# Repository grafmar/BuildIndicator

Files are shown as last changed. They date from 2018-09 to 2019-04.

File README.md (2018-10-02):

# Build Indicator
This device can show the state of builds or any other thing stored in the firebase database. It can
be configured, which part indicates what and lets the oportunity to meld fields together.

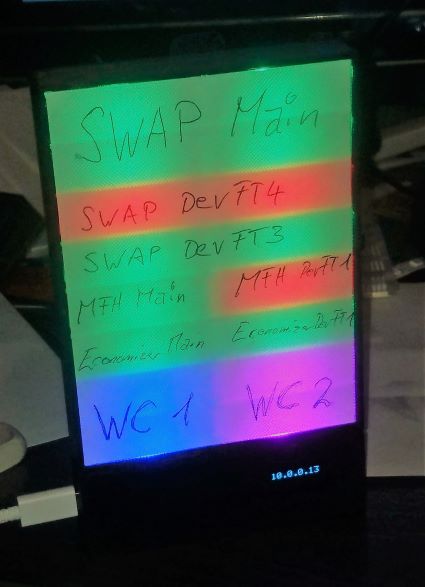
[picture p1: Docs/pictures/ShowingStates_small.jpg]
Build Indicator showing states


## Status
The actual status of the software is still buggy. It resets if the streaming from the firebase is activated.

## Requirements
* [Arduino IDE](https://www.arduino.cc/en/main/software)
* [ESP8266 board support](https://github.com/arduino/Arduino/wiki/Unofficial-list-of-3rd-party-boards-support-urls): http://arduino.esp8266.com/stable/package_esp8266com_index.json
* [FirebaseArduino library](https://github.com/FirebaseExtended/firebase-arduino)
* ArduinoJson library Version 5.13.1 (higher versions result in problems with the active FirebaseArduino library)
* Adafruit_NeoPixel library
* Adafruit_GFX library
* Adafruit_SSD1306 library
* WiFiManager library
* [Visual Studio](https://visualstudio.microsoft.com/) to have a comfortable IDE
* [Visual Micro](https://www.visualmicro.com/) to integrate Arduino IDE in Visual Studio

## Hardware
The hardware consists of:
* NodeMCU board (any ESP8266 board would do)
* WS2812b programmable RGB-LED stripes 2x8 in series
* SSD1306 OLED display (128x64 pixel)

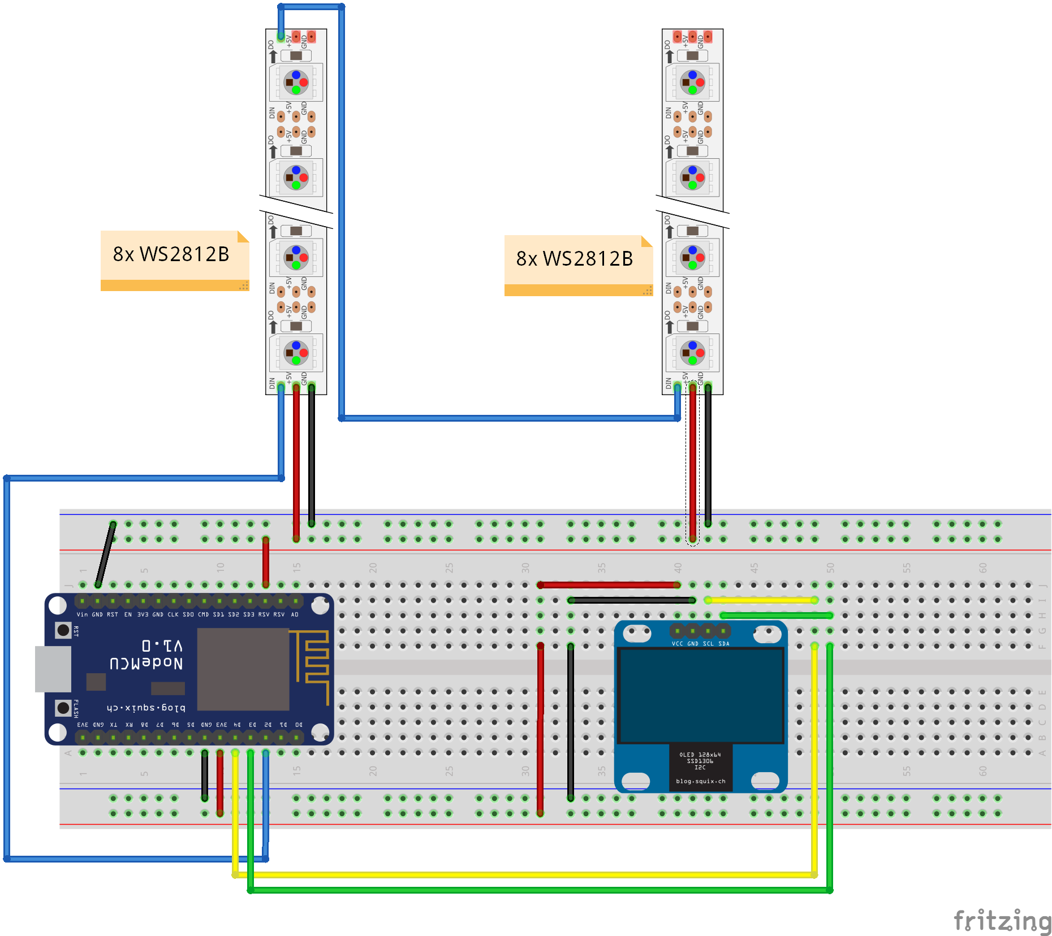
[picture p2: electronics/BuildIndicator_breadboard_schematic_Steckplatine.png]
Schematic


## Housing / Enclosure
The housing is printed using a 3D-Printer. There is a slit to slide in a transparent foil to write
the lamp configurations on. As background a transparent material can be used for the 3D-printer or
a thin paper which can be laminated for durability.
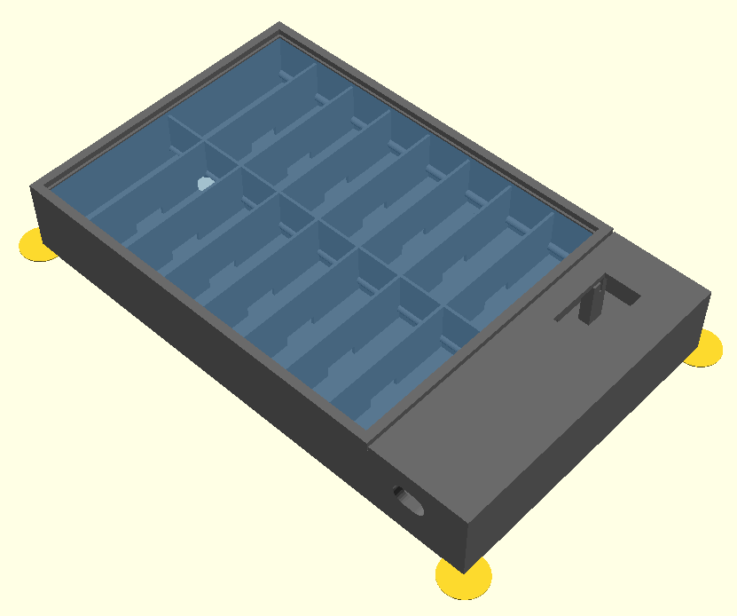
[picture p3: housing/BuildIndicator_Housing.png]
Housing complete

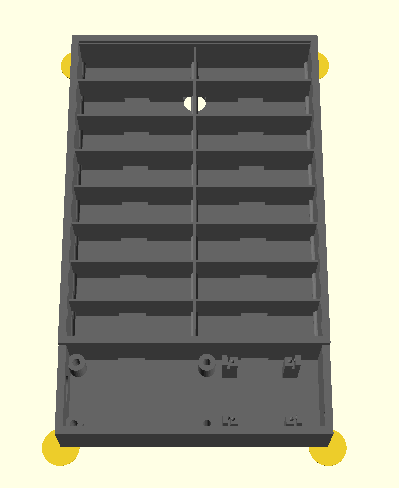
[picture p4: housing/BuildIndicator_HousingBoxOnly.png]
Housing box only


## Author
[Marco Graf](https://github.com/grafmar)

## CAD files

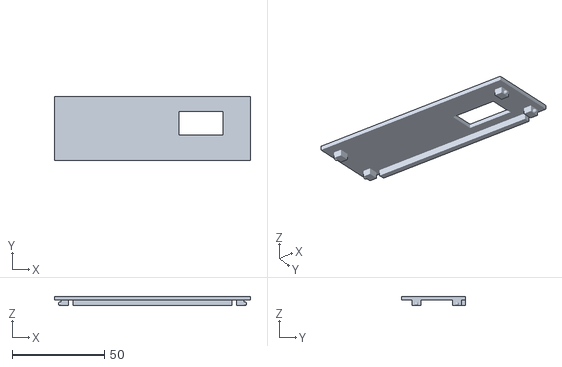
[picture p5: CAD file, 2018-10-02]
housing/BuildIndicatorBox_BoxCover.stl
106.0 x 34.5 x 5.00

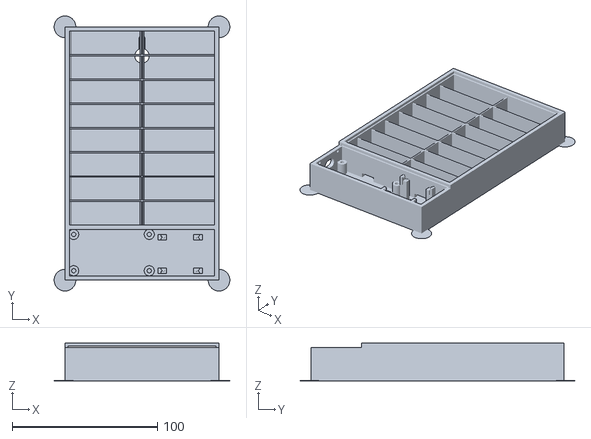
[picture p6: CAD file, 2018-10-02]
housing/BuildIndicatorBox_Box.stl
121.0 x 189.3 x 26.0

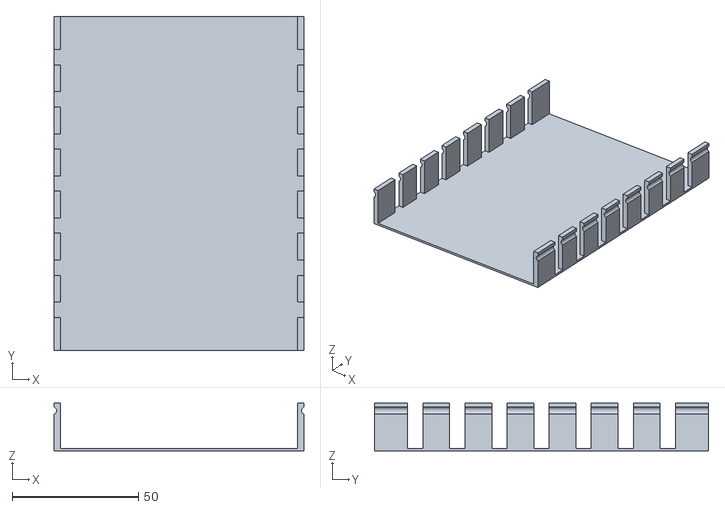
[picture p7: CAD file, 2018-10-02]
housing/BuildIndicatorBox_Diffusor.stl
99.0 x 132.3 x 19.0

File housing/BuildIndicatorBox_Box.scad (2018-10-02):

ledRows = 8;        // number of LED-rows
ledCols = 2;        // number of LED-columns
wall = 3;           // wall sickness [mm]
separator = 1;      // separator thickness [mm]
ledWidth = 50;      // width of 1 LED-indication segment
ledHeight = 50/3;   // height of 1 LED-indication segment (1.67mm LED pitch)
ledDepth = 20;      // depth of 1 LED indication segment (Box thickness = ledDepth+wall)
hookThickness = 2;

$fs=.5;
/*intersection(){
    translate([55,-40,-1]){cube([50,45,30]);}
    box();
}*/
box();
//translate([0,0,0]){boxCover();}
//translate([wall,ledHeight*ledRows+wall,ledDepth+wall]){rotate([180,0,0]){diffusor();}}
//diffusor();

/*
difference() {
    union() {
        box();
        translate([wall,ledHeight*ledRows+wall,ledDepth+wall]){rotate([180,0,0]){diffusor();}}
    }
    sphere(r=60,$fn=200);
}
*/

module hook() {
  translate([0,-2.5,-3]){cube([2, 5, 3],center=false);}
  hull() {
    translate([0,0,-2]){sphere(r=1);}
    translate([-0.5,0,-2]){sphere(r=1);}
  }
}

module boxCover() {
  boxWidth = ledWidth*ledCols + 2*wall;
  boxHeight = ledHeight*ledRows + 2*wall;
  dispCenterX = wall+3+52+10 + 22.5/2;
  dispCenterY = -32/2 -25/2 + 23/2 + 2.1;
  color("DimGray") {
    difference() {
      translate([0,-(32+wall),ledDepth+wall]){cube([boxWidth, 32+wall-0.5, 2]);}
      translate([dispCenterX, dispCenterY, ledDepth+wall]){cube([21.8+2, 10.9+2, 3*ledDepth], center=true);}
/*
    // Mounting holes Display
      -(32+wall)
    translate([wall+3+52+10,-32/2-25/2,wall]){nodeMCUMountingHole(ledDepth-3.5);}
    translate([wall+3+52+10,-32/2-25/2+23,wall]){nodeMCUMountingHole(ledDepth-3.5);}
    translate([wall+3+52+10+22.5,-32/2-25/2,wall]){nodeMCUMountingHole(ledDepth-3.5);}
    translate([wall+3+52+10+22.5,-32/2-25/2+23,wall]){nodeMCUMountingHole(ledDepth-3.5);}
*/
    }
    
    // stiffener
      translate([10,-wall-0.5,ledDepth]){cube([boxWidth-20, wall, wall]);}
    
    
    // hooks
    translate([wall+0.5,-32 + 5,ledDepth+wall]){hook();}
    translate([boxWidth-wall-0.5,-32 + 5,ledDepth+wall]){rotate([0,0,180]){hook();}}
    translate([wall+0.5,- 5,ledDepth+wall]){hook();}
    translate([boxWidth-wall-0.5,- 5,ledDepth+wall]){rotate([0,0,180]){hook();}}
  }
}

module box() {
  boxWidth = ledWidth*ledCols + 2*wall;
  boxHeight = ledHeight*ledRows + 2*wall;
    
  // Bodenhaltung
  bhDia=15;
  bhH=0.3;
  translate([0, -(32+wall),0]){cylinder(d=bhDia,h=bhH);}
  translate([boxWidth, -(32+wall),0]){cylinder(d=bhDia,h=bhH);}
  translate([0, boxHeight,0]){cylinder(d=bhDia,h=bhH);}
  translate([boxWidth, boxHeight,0]){cylinder(d=bhDia,h=bhH);}
  
  color("DimGray"){
    // LED-Part
    difference() {
      union() {
        difference() {
          cube([boxWidth, boxHeight, ledDepth+wall+3]);
          translate([wall,wall,wall]){cube([boxWidth-2*wall, boxHeight-2*wall, ledDepth+wall+3]);}
          // slit
          translate([wall-1,-1,ledDepth+wall]){cube([boxWidth-2*wall+2, boxHeight+2, 1]);}
        }
        // separators
        for(row=[1:ledRows-1]) {
          translate([0,wall+row*ledHeight-separator/2,0]){
            cube([boxWidth, separator, ledDepth+wall-2]);
          }
        }
        // separators
        for(col=[1:ledCols-1]) {
          translate([wall+col*ledWidth-separator/2,0,0]){
            cube([separator, boxHeight, ledDepth+wall-2]);
          }
        }
        // add hooks
        for(col=[0:ledCols]) {
          translate([wall+col*ledWidth,0,wall+2+2*separator]){
            rotate([-90,0,0]){cylinder(d=3*separator,h=boxHeight,$fs=.5);}
          }
        }
      }

      // Mounting hole
      translate([boxWidth/2,boxHeight-20,-wall+1]){cylinder(d=10,h=2*wall);}
      hull() {
        translate([boxWidth/2,boxHeight-20,-wall+1]){cylinder(d=4,h=2*wall);}
        translate([boxWidth/2,boxHeight-wall-5,-wall+1]){cylinder(d=4,h=2*wall);}
      }
      hull() {
        translate([boxWidth/2,boxHeight-20,wall+.001]){cylinder(d=10,h=4);}
        translate([boxWidth/2,boxHeight-wall-5,wall+.001]){cylinder(d=10,h=4);}
      }
      // LED-Stripe holes
      for(col=[0:ledCols-1]) {
        translate([wall+col*ledWidth-separator/2+ledWidth/2-11/2,-wall,wall]){
          cube([11, boxHeight, 3.5]);
        }
      }
    }
          
    // NodeMCU-Part
    translate([0,-(32+wall),0]) {
      difference() {
        cube([boxWidth, 32+wall, ledDepth+wall]);
        translate([wall,wall,wall]){cube([boxWidth-2*wall, 32+wall, ledDepth+wall]);}
        // USB-Plug hole
        hull() {
          translate([-1,wall+32/2+3,wall+9+2.7]){rotate([0,90,0]){cylinder(d=7,h=2*wall);}}
          translate([-1,wall+32/2-1,wall+9+2.7]){rotate([0,90,0]){cylinder(d=7,h=2*wall);}}
        }
        // hooks
        translate([wall+0.25, wall + 5,ledDepth+wall]){hook();}
        translate([boxWidth-wall-0.25, wall + 5,ledDepth+wall]){rotate([0,0,180]){hook();}}
        translate([wall+0.25, (32+wall) - 5,ledDepth+wall]){hook();}
        translate([boxWidth-wall-0.25, (32+wall)- 5,ledDepth+wall]){rotate([0,0,180]){hook();}}
      }
    }
    // Mounting holes NodeMCU
    translate([wall+3,-32/2+25/2,wall]){nodeMCUMountingHole(9);}
    translate([wall+3,-32/2-25/2,wall]){nodeMCUMountingHole(9);}
    translate([wall+3+52,-32/2+25/2,wall]){nodeMCUMountingHole(9);}
    translate([wall+3+52,-32/2-25/2,wall]){nodeMCUMountingHole(9);}
    // Mounting holes Display
    translate([wall+3+52+10,-32/2-25/2,wall]){displayMountingHole(ledDepth-3.5,180);}
    translate([wall+3+52+10,-32/2-25/2+23,wall]){displayMountingHole(ledDepth-3.5,180);}
    translate([wall+3+52+10+22.5,-32/2-25/2,wall]){displayMountingHole(ledDepth-3.5,0);}
    translate([wall+3+52+10+22.5,-32/2-25/2+23,wall]){displayMountingHole(ledDepth-3.5,0);}
  }
}

module nodeMCUMountingHole(height) {
    difference() {
        cylinder(d=7, h=height,center=false);
        cylinder(d=3, h=height+1,center=false);
    }
}

module displayMountingHole(height, rot=0) {
    rotate([0,0,rot]){
        translate([-2,-2,0]){cube([6,4,height-4]);}
        translate([-2,-2,0]){cube([3,4,height]);}
        translate([0,0,height]){sphere(d=1.5,$fn=20);}
        translate([2,-2,0]){cube([2,4,height+2.5]);}
        translate([2,0,height+1.75]){sphere(d=1.5,$fn=20);}
    }
}

module diffusor() {
  boxWidth = ledWidth*ledCols;
  boxHeight = ledHeight*ledRows;
  color( "SteelBlue", 0.3 ) {
    difference() {
      // one big cube
      translate([separator/2,separator/2,0]){
        cube([boxWidth-separator, boxHeight-separator, ledDepth-1]);
      }
      
      // substract col main volume
      for(col=[0:ledCols-1]) {
        translate([col*ledWidth+separator/2+hookThickness+separator/2,-1,1]){
          cube([ledWidth-2*hookThickness-2*separator, boxHeight+2, ledDepth]);
        }
      }
      // substract all inner hooks
      translate([separator+hookThickness,-1,1]){
        cube([boxWidth-2*separator-2*hookThickness, boxHeight+2, ledDepth]);
      }
      // substract row main volume
      /*for(row=[0:ledRows-1]) {
        translate([-1,separator+2+row*ledHeight,1]){
          cube([boxWidth+2, ledHeight-2*2-2*separator, ledDepth]);
        }
      }*/
      // substract spacing for row separators
      for(row=[1:ledRows-1]) {
        translate([-1,row*ledHeight-separator-2,1]){
          cube([boxWidth+2, 2*separator+4, ledDepth]);
        }
      }
      // substract spacing for col separators
      for(col=[1:ledCols-1]) {
        translate([col*ledWidth-separator,-1,1]){
          cube([2*separator, boxHeight+2, ledDepth]);
        }
      }
      // substract hook groove
      for(col=[0:ledCols]) {
        translate([col*ledWidth,0,ledDepth-2-2*separator]){
          rotate([-90,0,0]){cylinder(d=3*separator,h=boxHeight,$fs=.5);}
        }
      }
    }
  }
}

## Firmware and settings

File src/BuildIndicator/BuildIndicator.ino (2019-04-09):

#include "color.h"
#include "interpretation.h"
#include "BuildIndicator.h"
#include "configHandler.h"
#include <FirebaseArduino.h>
#include <ESP8266WiFi.h>
#include <ESP8266WebServer.h>
#include <WiFiManager.h>
#include <Adafruit_GFX.h>
#include <FS.h>


#include "displayHandler.h"
#include "htmlHandler.h"
#include "spiffsFile.h"
#include "firebaseHandler.h"
#include "configHandler.h"
#include "ledHandler.h"


// Set these to run example.
#define FIREBASE_HOST "yourHost.firebaseio.com"
#define FIREBASE_AUTH "TheVeryLongAuthenticationKeyForFirebase1"
#define FIREBASE_PATH "/yourPathToBuilds/"


ESP8266WebServer server(80);
ConfigHandler configHandler;
LedHandler ledHandler;
DisplayHandler displayHandler;
FirebaseHandler firebaseHandler(configHandler, ledHandler, displayHandler);


void setup() {
  Serial.begin(115200);
  
  // delay to sattle all voltages (for display)
  delay(2000);

  // Display Handler
  displayHandler.begin();

  // LED-Handler
  ledHandler.begin();

  // doit
  displayHandler.getDisplay().clearDisplay();
  displayHandler.getDisplay().setCursor(0,0);
  displayHandler.getDisplay().setTextSize(1);
  displayHandler.getDisplay().setTextColor(WHITE);
  
  setupSPIFFS();
  setupWifi();
  firebaseHandler.begin(FIREBASE_HOST, FIREBASE_AUTH, FIREBASE_PATH);
  //setupWebserver();
}


void loop() {
  //server.handleClient();
  firebaseHandler.handleEvents();
  displayHandler.handle();
}

void setupSPIFFS() {
  if (!SPIFFS.begin()) {
    Serial.println("Failed to mount file system");
  }
}

void setupWifi() {
  WiFiManager wifiManager;
  wifiManager.setTimeout(180);
  displayHandler.getDisplay().clearDisplay();
  displayHandler.getDisplay().setCursor(0,0);
  displayHandler.getDisplay().println("Connect to");
  displayHandler.getDisplay().println("\"BuildIndicatorAP\" to config WiFi");
  displayHandler.getDisplay().display();

  if (!wifiManager.autoConnect("BuildIndicatorAP")) {
    Serial.println("failed to connect and hit timeout");
    delay(3000);
    //reset and try again, or maybe put it to deep sleep
    ESP.reset();
    delay(5000);
  }

  Serial.println("IP address: ");
  Serial.println(WiFi.localIP());
  displayHandler.getDisplay().clearDisplay();
  displayHandler.getDisplay().setCursor(0,0);
  displayHandler.getDisplay().println("my IP: ");
  displayHandler.getDisplay().println();
  displayHandler.getDisplay().setTextSize(2);
  displayHandler.getDisplay().println(WiFi.localIP());
  displayHandler.getDisplay().display();
}

void setupWebserver() {
  // handle requests
  server.on("/", HTTP_GET, []() {
    htmlPrintSetting(server, NUM_OF_PIXEL_ROWS, NUM_OF_PIXEL_COLS, firebaseHandler);
  });
  server.on("/editKeys", HTTP_GET, []() {
    htmlEditKeys(server, NUM_OF_PIXEL_ROWS, NUM_OF_PIXEL_COLS, firebaseHandler);
  });
  server.on("/editInterpret", HTTP_GET, []() {
    htmlEditInterpret(server, NUM_OF_PIXEL_ROWS, NUM_OF_PIXEL_COLS, firebaseHandler);
  });
  server.on("/save", HTTP_POST, []() {
    htmlSaveSetting(server, NUM_OF_PIXEL_ROWS, NUM_OF_PIXEL_COLS, firebaseHandler);
  });
  server.on("/saveInterpret", HTTP_POST, []() {
    htmlSaveInterpret(server, NUM_OF_PIXEL_ROWS, NUM_OF_PIXEL_COLS, firebaseHandler);
  });
  server.on("/list", HTTP_GET, []() {
    htmlPrintDirectory(server);
  });

  server.onNotFound([]() {
    Serial.printf("request: %s\n", server.uri().c_str());
    if(!handleFileRead(server.uri(), server))
      server.send(404, "text/plain", "FileNotFound");
  });
  
  server.begin();
}

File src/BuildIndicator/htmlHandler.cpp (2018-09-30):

#include <FS.h>

#include "htmlHandler.h"

uint16_t handleEditKeys(bool doSend, ESP8266WebServer &server, uint8_t rows, uint8_t cols, std::list<String> &buildsAvailable, String* buildKeys);
uint16_t handleEditInterpret(bool doSend, ESP8266WebServer &server, uint8_t rows, uint8_t cols, std::list<Interpretation>& interpretations);

uint8_t hexChar2byte(char input) {
  if (input >= '0' && input <= '9')
    return input - '0';
  if (input >= 'A' && input <= 'F')
    return input - 'A' + 10;
  if (input >= 'a' && input <= 'f')
    return input - 'a' + 10;
  return 0;
}

Color htmlColorToColor(const char* htmlColor) {
  uint8_t red   = hexChar2byte(htmlColor[1]) * 16 + hexChar2byte(htmlColor[2]);
  uint8_t green = hexChar2byte(htmlColor[3]) * 16 + hexChar2byte(htmlColor[4]);
  uint8_t blue  = hexChar2byte(htmlColor[5]) * 16 + hexChar2byte(htmlColor[6]);
  return Color(red, green, blue);
}

void htmlPrintSetting(ESP8266WebServer &server, uint8_t rows, uint8_t cols, FirebaseHandler& fbHandler) {
  String* buildKeys = fbHandler.getBuildKeys();
  Color* colors = fbHandler.getColors();
  String output = "<!DOCTYPE html>\n<html>\n<head>\n<meta charset=\"utf-8\">\n";
  output += "<title>IndicationLamps</title>\n<meta name=\"viewport\" content=\"width=device-width, initial-scale=1\">\n";
  output += "<link rel=\"stylesheet\" type=\"text/css\" href=\"indicationLamps.css\">\n";
  output += "<style>\n";
  output += "td.shadow{ color: #EEEEEE; text-shadow: 0px 0px 2px #000000; text-shadow: 0px 0px 5px #000000; padding:  0.7em 1em 0.7em 1em; }\n";
  output += "</style>\n";
  output += "</head>\n";
  output += "<body class=\"body\">\n";

  output += "<div class='table'>\n";
  output += "<table width='100%' border='1'>\n";
  for (uint8_t col=0; col<cols; col++) {
    output += "<col width='" + String(100/cols, DEC) + "%'>\n";
  }
  for (uint8_t row=0; row<rows; row++) {
    output += "<tr>\n";
    for (uint8_t col=0; col<cols; col++) {
      char colorString[10];
      sprintf(colorString, "%02x%02x%02x", colors[row + col*rows].r, colors[row + col*rows].g, colors[row + col*rows].b);
      output += "<td class='shadow' style='background: #"+String(colorString)+";'><b>";
      output += buildKeys[row + col*rows];
      output += "</b></td>\n";
    }
    output += "</tr>\n";
  }
  output += "</table><br>\n";
  output += "<a href='/editKeys'>Edit the shown builds/keys</a><br><br>\n";
  output += "<a href='/editInterpret'>Edit the interpreted values</a><br>\n";
  output += "</div>\n";
  
  output += "\n</body>\n</html>\n";
  server.send(200, "text/html", output);
  fbHandler.updateListOfBuilds();
}


void htmlEditKeys(ESP8266WebServer &server, uint8_t rows, uint8_t cols, FirebaseHandler& fbHandler) {
	String* buildKeys = fbHandler.getBuildKeys();
	std::list<String> buildsAvailable = fbHandler.listBuilds();
  
  uint16_t contentLength = handleEditKeys(false, server, rows, cols, buildsAvailable, buildKeys);
	//now send an empty string but with the header field Content-Length to let the browser know how much data it should expect
  server.setContentLength(contentLength);
  server.send(200, "text/html", "");
  static_cast<void>(handleEditKeys(true, server, rows, cols, buildsAvailable, buildKeys));
}

uint16_t handleEditKeys(bool doSend, ESP8266WebServer &server, uint8_t rows, uint8_t cols, std::list<String> &buildsAvailable, String* buildKeys) {
  uint16_t totalLength = 0;
	String output = "<!DOCTYPE html>\n<html>\n<head>\n<meta charset=\"utf-8\">\n<title>IndicationLamps Configuration</title>\n<meta name=\"viewport\" content=\"width=device-width, initial-scale=1\"><link rel=\"stylesheet\" type=\"text/css\" href=\"indicationLamps.css\">\n</head>\n<body class=\"body\">\n";
  totalLength += output.length();
  if (doSend) { server.sendContent_P(output.c_str(), output.length()); }

  output = "<div class='table'>\n";
  output += "<form action='/save' method='post'>\n";
  output += "<table width='100%' border='1'>\n";
  for (uint8_t col=0; col<cols; col++) {
    output += "<col width='" + String(100/cols, DEC) + "%'>\n";
  }
  totalLength += output.length();
  if (doSend) { server.sendContent_P(output.c_str(), output.length()); }
  for (uint8_t row=0; row<rows; row++) {
    output = "<tr>\n";
    for (uint8_t col=0; col<cols; col++) {
      output += "<td>";
      output += "<select id='" + String(row + col*rows, DEC) + "' name='" + String(row + col*rows, DEC) + "'>\n";
      for (String build : buildsAvailable) {
        output += "<option value='" + build + "'";
        if (build == buildKeys[row + col*rows]) {
          output += " selected";
        }
        output += ">" + build + "</option>\n";
      }
      output += "</select>";
      if (col < cols-1) {
        output += "<button type='button' onclick='document.getElementById(\""
                  + String(row + (col+1)*rows, DEC)
                  + "\").selectedIndex=document.getElementById(\""
                  + String(row + col*rows, DEC)
                  + "\").selectedIndex'>-&gt;</button>";
      }
      output += "</td>\n";
    }
    output += "</tr>\n";
    totalLength += output.length();
    if (doSend) { server.sendContent_P(output.c_str(), output.length()); }
  }
  output = "</table>\n";
  output += "<input type='submit' value='Save configuration'><br>";
  output += "</form>\n";
  output += "</div>\n";
  
  output += "\n</body>\n</html>\n";
  totalLength += output.length();
  if (doSend) { server.sendContent_P(output.c_str(), output.length()); }

  return totalLength;
}

void htmlEditInterpret(ESP8266WebServer &server, uint8_t rows, uint8_t cols, FirebaseHandler& fbHandler) {
  std::list<Interpretation>& interpretations = fbHandler.getInterpretations();

  uint16_t contentLength = handleEditInterpret(false, server, rows, cols, interpretations);
  // now send an empty string but with the header field Content-Length to let the browser know how much data it should expect
  server.setContentLength(contentLength);
  server.send(200, "text/html", "");
  static_cast<void>(handleEditInterpret(true, server, rows, cols, interpretations));
}
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

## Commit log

2018-09-30 Add all files
    [buildKeys.cfg, interpretations.cfg]
2018-10-01 Moved source code to src/BuildIndicator
    [buildKeys.cfg, interpretations.cfg]
2018-10-02 Added picture of schematic
    [BuildIndicator_breadboard_schematic.fzz]
2018-10-02 Added housing to repository
    [BuildIndicatorBox_Box.scad, BuildIndicatorBox_Box.stl, BuildIndicatorBox_BoxCover.stl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]
2019-04-09 Applied corrections on includes
    [BuildIndicator.ino]
